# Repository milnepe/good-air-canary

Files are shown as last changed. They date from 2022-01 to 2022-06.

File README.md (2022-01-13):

# good-air-canary
An Arduino IoT client for DesignSpark ESDK that reacts to environmental C02 levels

Full details of the build can be found on [DesignSpark](https://www.rs-online.com/designspark/good-air-canary-build-guide).
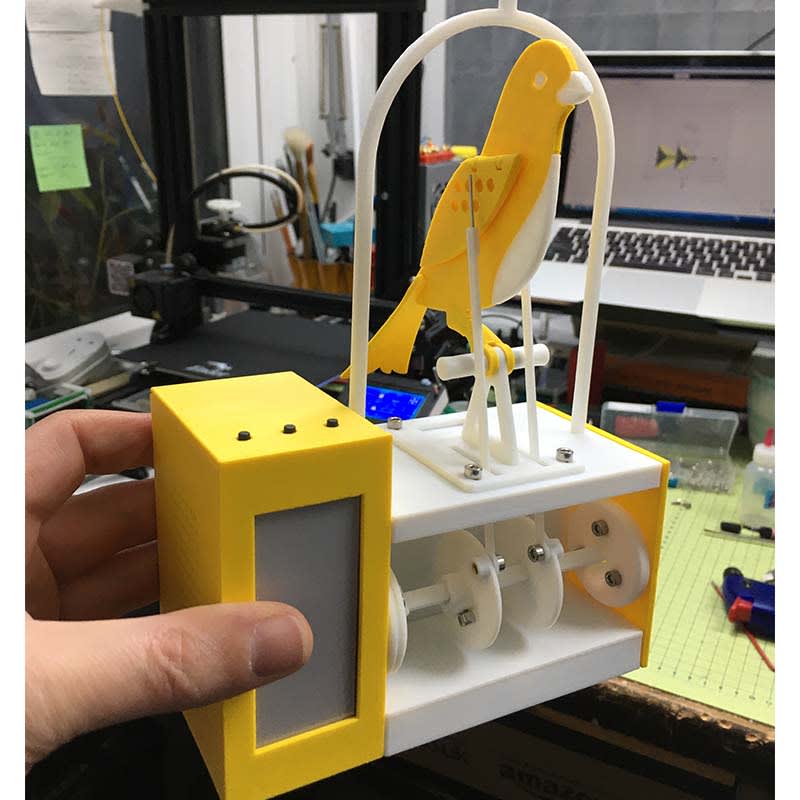
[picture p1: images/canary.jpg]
Canary


Prototype circuit in article on [DesignSpark](https://www.rs-online.com/designspark/the-good-air-canary-controller-build-guide).
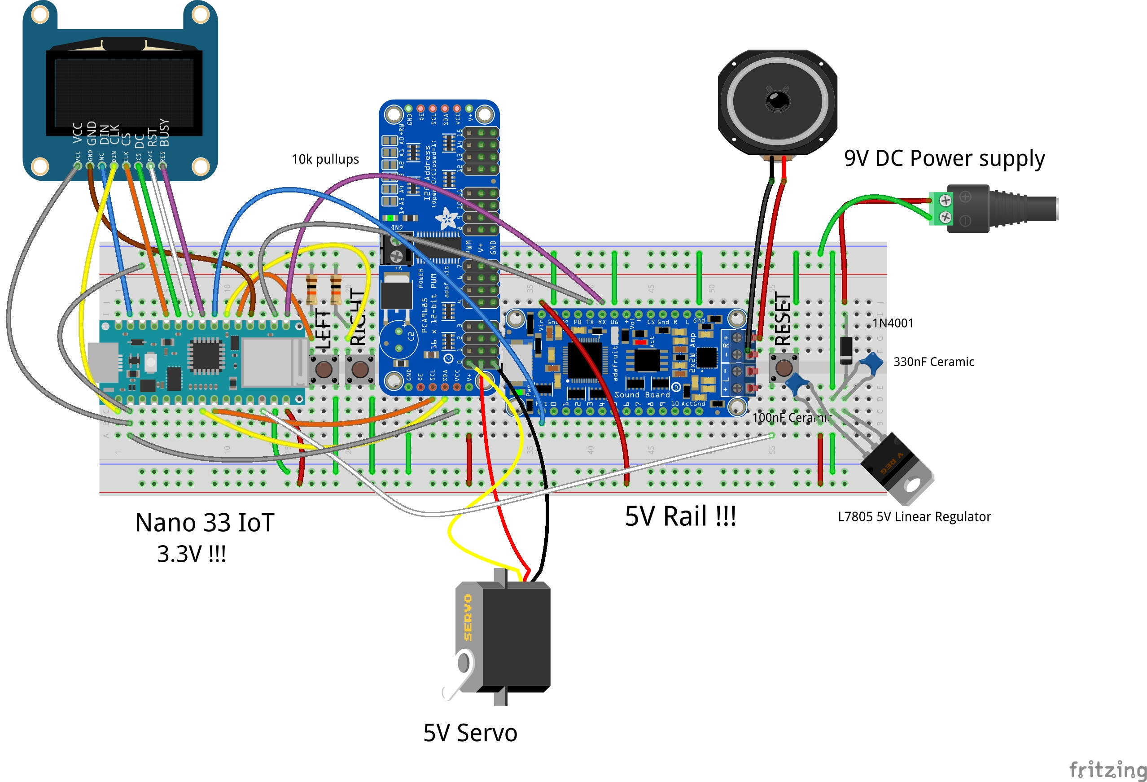
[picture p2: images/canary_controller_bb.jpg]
Canary controller circuit


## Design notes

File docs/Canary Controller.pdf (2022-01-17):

# The Good Air Canary Controller

An Arduino IoT client for DesignSpark ESDK that reacts to environmental CO2 levels

The DesignSpark Environmental Sensor Development Kit (ESDK) uses its attached sensors to collect CO2 levels in the surrounding environment. It sends this to a cloud dashboard so the data can be viewed and analysed.

Jude Pullen came up with the idea to create a model canary that could react to different levels of CO2 in the atmosphere and perform animations, like flapping its wings and falling off the perch when things got really bad. We also gave it a voice, just for good measure.

The device is really an IoT client for the ESDK. It’s powered by an Arduino microcontroller that receives messages containing the sensor readings via WiFi every time the ESDK updates them. The canary checks the CO2 level and if it’s too high it triggers one of its actions. For example, flapping its wings gently and asking you to open a window politely.

If you ignore its advice, it will become more and more agitated and vocal, before diving off its perch when it can take no more. If it gets to this stage, you really should open the windows for your own well being!

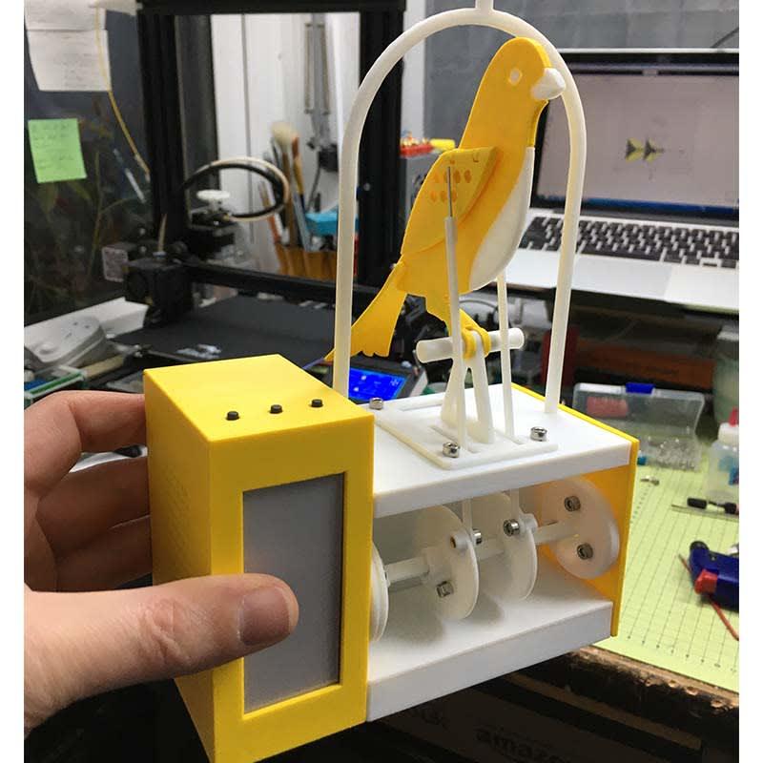
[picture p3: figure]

Difficulty: Medium

Steps: 7

Credit: Pete Milne

License: GNU Lesser General Public License

Parts Needed:

Part | Description | Stock No | Cost
Nano 33 IOT | https://uk.rs-online.com/web/p/arduino/1927589/ Available with and without headers. | 192-7589 | £18.04
5V Servos | TowerPro Servo Motor - SG90 Analog (https://thepihut.com/products/towerpro-servo-motor-sg90-analog) | 103049 | £4.00
Servo Driver | Adafruit 16-Channel 12-bit PWM/Servo Driver - I2C interface (https://www.adafruit.com/product/815) | ADA815 | £14.50
Sound board + Amp | Adafruit Audio FX Sound Board + 2x2W Amp - WAV/OGG Trigger - 2MB (https://www.adafruit.com/product/2217) | ADA2210 | £24.10
Speakers | Stereo Enclosed Speaker Set - 3W 4 Ohm (https://thepihut.com/products/stereo-enclosed-speaker-set-3w-4-ohm) RS have speakers in stock which may also be suitable | 102797 | £ 6.50
5V Linear Regulator | STMicroelectronics, 5 V Linear Voltage Regulator, 1A, 1-Channel, 2% 3-Pin, TO-220 L7805ABV (https://uk.rs-online.com/web/p/voltage-regulators/1686612/) | 686-9820 | £0.42
1N4001 Diode | Vishay 50V 1A, Diode, 2-Pin DO-204AL 1N4001-E3/54 (https://uk.rs-online.com/web/p/schottky-diodes-rectifiers/6288931/) | 628-8931 | £0.18
0.33uF Cap | 0.33uF Ceramic Capacitor
0.1uF Cap | 0.1uf Ceramic Capacitor
Power Supply | 9V / 500mA DC power supply or similar
Power Supply Connector | Female DC Power adapter - 2.1mm jack to screw terminal block (https://www.amazon.co.uk/Adafruit-2-1mm-Female-Terminal-Adapter/dp/B00KAE1QGS) | 102858 | £1.70
E-Ink Display | 296x128, 2.9inch E-Ink display module (https://www.waveshare.com/product/displays/e-paper/epaper-2/2.9inch-e-paper-module.htm) | | £20.00
Breadboard | Generic breadboard

# Step 1: Arduino MCU

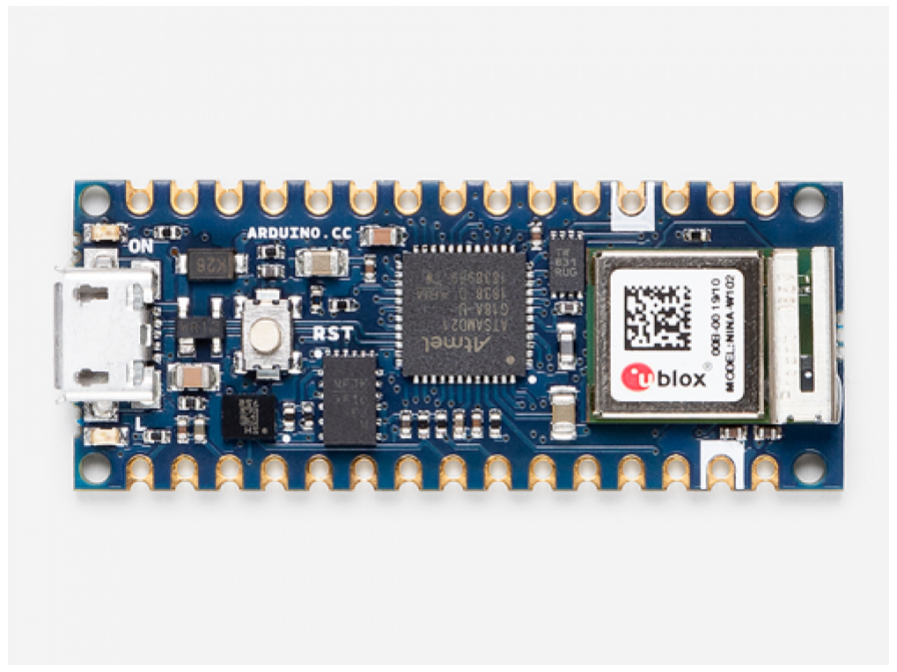
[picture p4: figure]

At the centre of the hardware is the Arduino Nano 33 IoT board. This has a SAMD21 Cortex®-M0+ 32bit ARM MCU with 256KB flash memory and a u-blox NINA-W102 Wifi module.

The board connects to Wifi, runs an MQTT client that receives the sensor data from the ESDK, processes the JSON messages and controls a servo to actuate the canary through a clever mechanical mechanism. The servo is driven by a PWM servo control board and high quality audio is provided by a dedicated audio board with a built in amplifier and single speaker attached.

# Step 2: Prototype circuit

The circuit can be built up and tested in stages to make sure that each component is working before adding the next. Just take care with voltage levels. Here are the main components:

Warning: The Arduino Nano GPIO operates at 3.3V and the circuit also uses 5V for some components - be careful not to connect 5V to the Arduino GPIO or you will damage it!

- Adafruit 16-Channel 12-bit PWM Servo Driver

This board operates at 3.3V (VCC) powered from the 3.3V pin on the Arduino. The servo has a separate 5V supply (V+) from the linear regulator. Communication is via an I2C interface using a driver library from the manufacturer. Originally we thought that we might need more than one servo for the canary, as it worked out we didn’t but we left the board in the design as it simplifies the hardware and programming.

- TowerPro SG90 Analog Servo Motor

This operates the wing mechanism of the canary

- Adafruit Audio 2MB FX Sound Board with Amp

Plays 44.1KHz 16 bit OGG format sound clip recordings that are pre-loaded onto the device in USB mass storage mode. It uses a serial interface operating at 9600 baud controlled by the Arduino using a driver library provided by the manufacturer.

- 4 Ohm / 3W Stereo Enclosed Speaker

We purchased a set of two speakers as the sound board supports stereo but it was decided to just use the one speaker for a compact design.

Note: Use 4 - 8 Ohm impedance speakers and to keep the cable length to less than 10 cm

- L7805 powers linear regulator and capacitors

We built in an independent 5V power supply to power the Arduino (via VIN) and for the audio board and servo. You may be able to get away with using the USB connector on the Arduino to supply the circuit, depending on your servo power requirements but it will be at the upper limit safe to use with the Arduino.

- 2.9 inch E-ink display from Waveshare

We wanted a contemporary display to show all the sensor readings received from the ESDK. The display was tricky to program and we had issues with the hardware versions being different, even though they had the same part number. The code libraries also seem to change during development so we have included the working version in our GitHub for the project.

Note: The E-ink display code and library version only works for Waveshare 2.9in Black & White displays marked V2

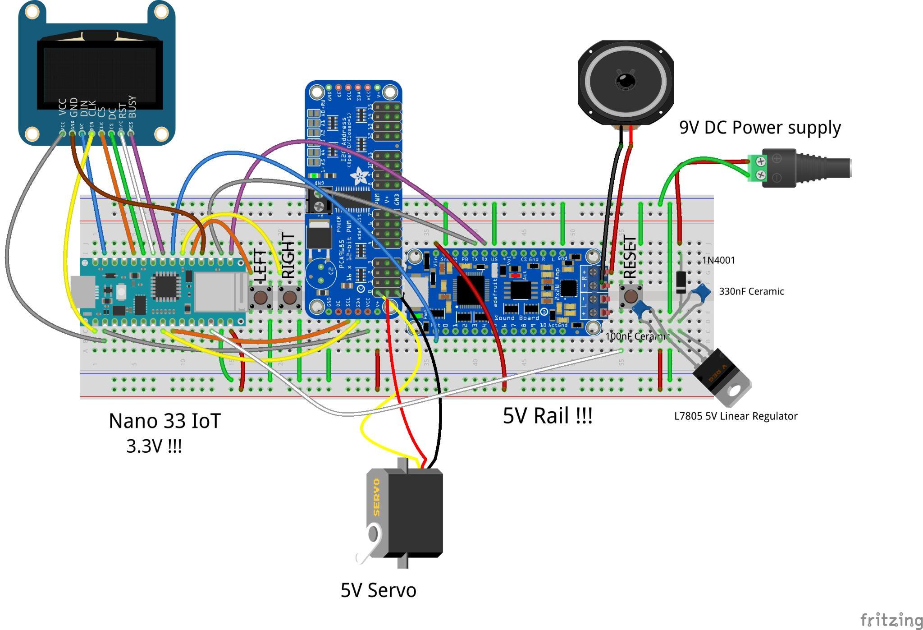
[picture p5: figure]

Here’s an image of the prototype circuit being tested with an early prototype the ESDK - you can see the ESDK between the screen and keyboard and the canary circuit to the right. The screen is showing the JSON messages being received from the ESDK in the Terminal.

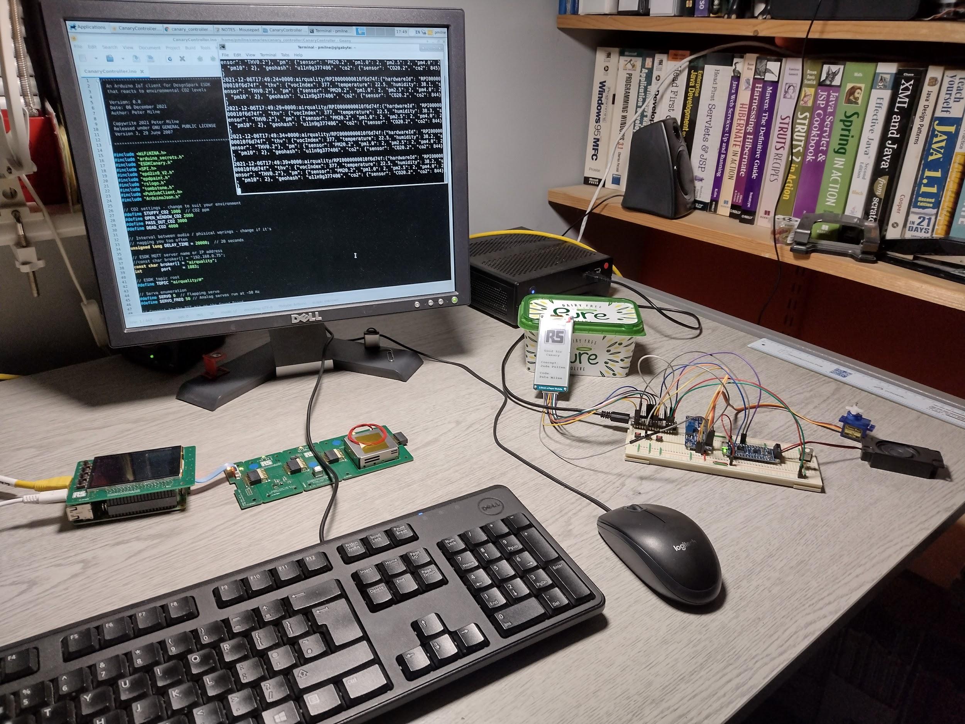
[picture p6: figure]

# Step 3: Arduino sketch

Programming and flashing the Arduino IDE was done using the Arduino IDE. The full source code is available on the DesignSpark GitHub:

https://github.com/DesignSparkRS/good-air-canary

Download the zip file or clone the repo to your Windows / Mac / Linux or Raspberry Pi.

You will need to install a number of different Libraries into the IDE using the Library Manager before you can compile and upload the code to the Arduino:

- Arduino WiFiNINA library
- Adafruit Soundboard library
- Adafruit PWM Servo Driver Library
- ArduinoJson - not Arduino_JSON which didn’t handle the large JSON payload well
- PubSubClient

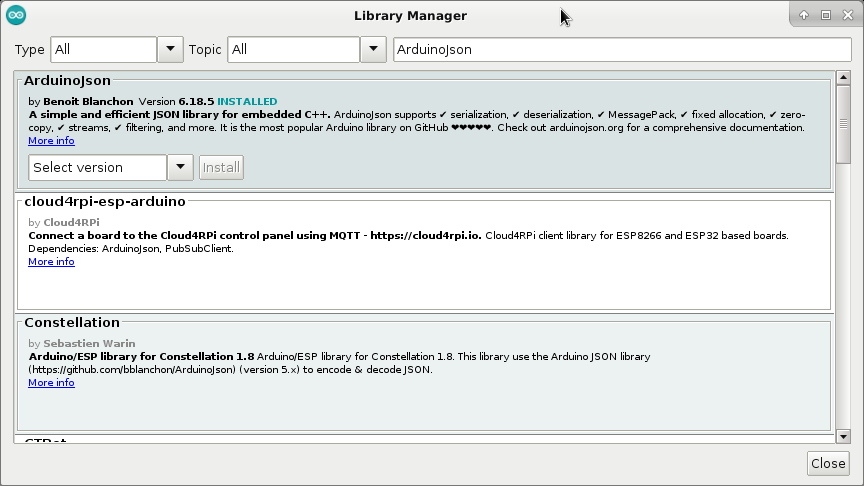
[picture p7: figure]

Attaching the Arduino to your Wifi will require editing the following lines in the arduino_secrets.h file which should appear in one of the tabs in the IDE.

Change the define statements to match your own Wifi SSID & password (with inverted commas):

### #define SECRET_SSID "YOURSSID"

### #define SECRET_PASS "YOURPASSWORD"

Depending on your network, you may need to change the default hostname of the ESDK. This is in CanaryController.ino. Change the character string from “airquality” the IP address of the ESDK on your network. You can find this by logging into your router as administrator and looking at the connected devices.

### // ESDK server name or IP address

//const char broker[] = "192.168.0.75";
const char broker[] = "airquality";

You can change the frequency with which the canary checks CO2 levels. For testing we set it to every 20 seconds but you may want to extend this by updating the define statement, in milli-seconds:

### // Interval between audio / physical warings - change if it's

### // nagging you too often

### unsigned long DELAY_TIME = 20000; // 20 seconds

Once all these changes have been made you should be able to compile and upload the code to your Arduino, then open the serial monitor to see debugging information.

When the system boots it displays the credits screen, initialises the servo and sound board, then plays a “yawn” sound clip. The Arduino then tries to connect to the network and if successful, subscribes to the ESDK’s MQTT server, where it waits for the first messages to appear. At that point the screen will start to display the sensor readings from the ESDK.

Periodically the canary evaluates the CO2 level data received and performs one of its actions according to the current level.

If you ignore the canary it will get persistently more agitated until it keels over. Don’t let that happen as it’s bad for your health and you will have to reset the Arduino, which is intentional!

# Step 4: MQTT

If you have a Linux box or a Raspberry Pi you can view the MQTT message payload coming from the ESDK by subscribing to its MQTT server.

Make sure you have the mosquitto-clients package installed:

### sudo apt install mosquitto-clients

Subscribe to the ESDK service using the following command:

### mosquitto_sub -F '%I:%t:%p' -h airquality -t airquality/#

You should see the JSON payload update every 5 seconds, similar to the output below:

# Step 5: Servo tuning

Each servo behaves slightly differently so you may need to tune the parameters to suit your servo. Do this by adjusting the following define statements in the ESDKCanary.h file which should appear as one of the tabs in your IDE:

### #define WINGS_DOWN 495

### #define WINGS_UP 445

### #define PASS_OUT_POS 225

### #define DEAD_POS 150

Tweak the settings by a small amount and then re-compile your code until the canary movement is correct and your servo is not chattering.

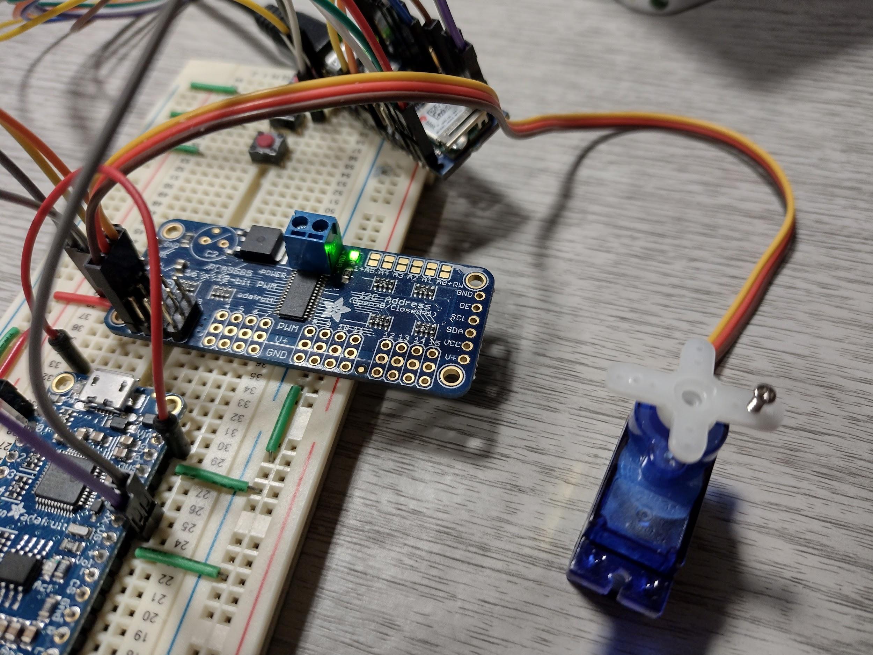
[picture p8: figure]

# Step 6: Sound effects

Our sound effect files were recorded on a windows PC in M4A format. They were converted to Ogg Vorbis format on a Linux box or Raspberry Pi using ffmpeg (other converters are available).

Make sure the ffmpeg package is installed:

## sudo apt install ffmpeg

This command, used in the Terminal converts the “yawn” clip in M4A format to the Ogg Vorbis format using the naming convention required by the sound board:

## ffmpeg -i yawn.m4a T00.ogg

The board can play upto 9 different files, which must have a specific naming convention. The first file is named T00.ogg, second T01.ogg etc.

Before the board is installed into the circuit, flash the Ogg sound clips onto the soundboard’s EPROM by attaching it to your PC with a USB cable and copying the files using a file manager or terminal.

You can record your own sound effects or use the ones provided in a Pytonesque voice over - let your creative side go wild!

Small 4 Ohm / 3 W speaker attached on short cable

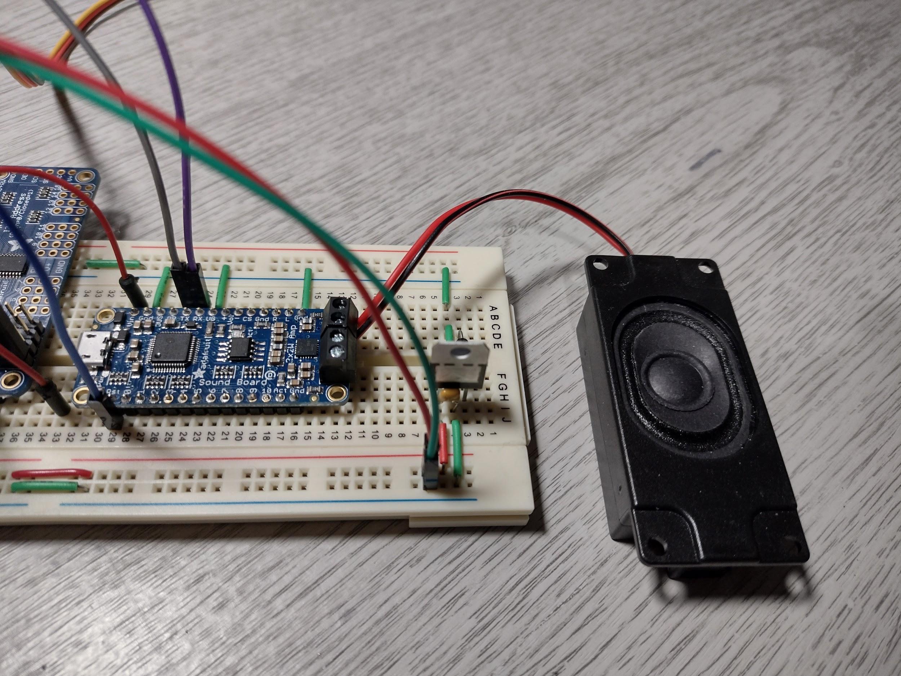
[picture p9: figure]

# Step 7: Buttons

There are now 2 buttons (Left & Right) which can be used to enable / disable the audio. They use 10k external pullup resistors and are connected to GND.

Left Button: Pin D2 -> Button -> GND

Right Button: Pin D3 -> Button -> GND

The Centre button is connected to the Arduino Reset pin and GND. This resets the whole board. When the screen clears for 5 seconds is a good time to disconnect the power to preserve the e-paper display.

Centre button: Reset -> Button -> GND

# Step 8: Troubleshooting

The Arduino IDE serial monitor is your friend when finding out what’s going on with your firmware. We included loads of serial output to help with debugging.

If you have trouble, uncomment the DEBUG define at the top of CanaryController.ino and reflash the code. You will need to open the Serial Monitor before the code will run. You should see helpful error messages which will help in tracking down any issues.

## // Un-comment for all debug prints

## // You will also need to attach a serial monitor before

## // the system will start up

## #define DEBUG

Here are a few common issues and how to solve them:

- Arduino is not connecting to the network

Change the “airquality” hostname to the IP address of the ESDK and reflash the code.

- Canary screen continues to display the credits screen

Check that the ESDK is on the same network if you have more than one and that you can subscribe to its MQTT messages using the method in step 4.

- Canary is not moving correctly

Check the servo parameters are suitable for your servo as in Step 5

- The sound board makes a popping sound but sound clips don’t play

Check you have set it to use 9600 baud rate in the setup section of CanaryController.ino

- E-Ink display is blank

Check you have the V2 version of the 2.9in Waveshare display

- MQTT messages are not being processed

Make sure you have enough memory allocated to hold the JSON document in the MQTT callback function

### // ESDK sends a large JSON payload

### // - ensure you have enough memory allocated

StaticJsonDocument<384> doc;

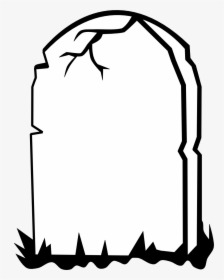
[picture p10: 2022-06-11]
images/tombstone.jpg

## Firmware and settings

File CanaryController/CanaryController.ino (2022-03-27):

/***************************************************
  An Arduino IoT client for DesgnSpark ESDK
  that reacts to environmental CO2 levels

  Version: 2.0
  Date: 27 March 2022
  Author: Peter Milne

  Copyright 2022 Peter Milne
  Released under GNU GENERAL PUBLIC LICENSE
  Version 3, 29 June 2007

 ****************************************************/
// Un-comment for debugging
// In debug mode the system will not run until a serial monitor
// is attached!
//#define DEBUG

#include <WiFiNINA.h>
#include "arduino_secrets.h"
#include "ESDKCanary.h"
#include <SPI.h>
#include "epd2in9_V2.h"
#include "epdpaint.h"
#include "rslogo.h"
#include "tombstone.h"
#include <PubSubClient.h>
#include "ArduinoJson.h"

// CO2 levels - change to suit your environment
#define STUFFY_CO2 1000  // CO2 ppm
#define OPEN_WINDOW_CO2 2000
#define PASS_OUT_CO2 3000
#define DEAD_CO2 4000

#define NORMAL_DELAY 30 * 60 * 1000  // 30 mins default
#define DEMO_DELAY 10 * 1000    // 10 sec for debug

#ifdef DEBUG
volatile unsigned long delay_time = DEMO_DELAY;
#else
// Interval between audio / physical warnings - change if it's
// nagging you too often
unsigned long delay_time = NORMAL_DELAY;
#endif
unsigned long previousMillis = 0;

// ESDK MQTT server name
// You may need to substiture its IP address on your network
//const char broker[] = "192.168.0.75";
const char broker[] = "airquality";
int        port     = 1883;

// ESDK topic root
#define TOPIC "airquality/#"

#define SERVO 0  // Flapping servo
#define SERVO_FREQ 50 // Analog servos run at ~50 Hz

// Connect to the RST pin on the Sound Board
#define SFX_RST 4

#define COLORED     0
#define UNCOLORED   1

unsigned char image[1024];
Paint paint(image, 0, 0);    // width should be the multiple of 8
Epd epd; // default reset: 8, dc: 9, cs: 10, busy: 7

/////// Enter sensitive data in arduino_secrets.h
char ssid[] = SECRET_SSID;  // Network SSID
char pass[] = SECRET_PASS;  // WPA key

WiFiClient wifiClient;
long lastReconnectWIFIAttempt = 0;
PubSubClient mqttClient(wifiClient);
long lastReconnectMQTTAttempt = 0;

Adafruit_PWMServoDriver pwm = Adafruit_PWMServoDriver();  // Default address 0x40

Adafruit_Soundboard sfx = Adafruit_Soundboard(&Serial1, NULL, SFX_RST);

ESDKCanary myCanary = ESDKCanary();

//unsigned long delayStart = 0; // time the delay started
bool delayRunning = false; // true if still waiting for delay to finish

volatile int co2 = 400;
double temperature = 21.0;
double humidity = 40.0;
int tvoc = 100;
int pm = 1;

volatile bool updateDisplayFlag = false;
bool tombstoneFlag = false;

uint16_t pulselen = 0;
int prevSensorValue = 0;

enum states {NORMAL, STUFFY, OPEN_WINDOW, PASS_OUT, THATS_BETTER, DEAD} state = NORMAL;
enum states previousState = NORMAL;

// Button code
enum buttons {LEFT_BUTTON = 2, RIGHT_BUTTON = 3, DEMO_BUTTON = 9};
volatile boolean audioOn = true;
volatile boolean demo_mode = false;
volatile boolean reentrant = true;

int wifiState = WL_IDLE_STATUS;

void setup() {
  // Setup buttons
  pinMode(LEFT_BUTTON, INPUT);
  pinMode(RIGHT_BUTTON, INPUT);
  pinMode(DEMO_BUTTON, INPUT);
  //  pinMode(isrLED, OUTPUT);
  //  digitalWrite(isrLED, HIGH);
  attachInterrupt(digitalPinToInterrupt(LEFT_BUTTON), leftButtonIsr, FALLING);
  // DEMO_BUTTON duplicates the RIGHT_BUTTON function - activates demo
  attachInterrupt(digitalPinToInterrupt(RIGHT_BUTTON), rightButtonIsr, FALLING);
  attachInterrupt(digitalPinToInterrupt(DEMO_BUTTON), rightButtonIsr, FALLING);

  Serial.begin(115200);
#ifdef DEBUG
  while (!Serial) {
    ; // wait for serial port to connect
  }
#endif
  Serial.println("Canary Controller");

  Serial1.begin(9600);
  while (!Serial1) {
    ; // wait for serial port to connect
  }
  Serial.println("Serial1 attached");

  if (epd.Init() != 0) {
    Serial.print("e-Paper init failed ");
    return;
  }
  Serial.println("EDP attached");

  epd.ClearFrameMemory(0xFF);   // bit set = white, bit reset = black
  epd.DisplayFrame();

  /**
      there are 2 memory areas embedded in the e-paper display
      and once the display is refreshed, the memory area will be auto-toggled,
      i.e. the next action of SetFrameMemory will set the other memory area
      therefore you have to set the frame memory and refresh the display twice.
  */
  epd.SetFrameMemory_Base(RSLOGO);
  epd.DisplayFrame();

  updateEPDGreeting();

  // Setup sound board
  if (!sfx.reset()) {
    Serial.println("SFX board not found");
    //while (1);
  }
  else Serial.println("SFX board attached");
  myCanary.Tweet(sfx, YAWN_TRACK);

  // Setup servo
  pwm.begin();
  pwm.setOscillatorFrequency(27000000);
  pwm.setPWMFreq(SERVO_FREQ);  // Analog servos run at ~50 Hz updates
  myCanary.ServoInit(pwm, SERVO);
  Serial.println("Servo initialised");

  Serial.print("Attempting to connect to the MQTT broker: ");
  Serial.println(broker);

  mqttClient.setServer(broker, port);
  mqttClient.setCallback(callback);
  mqttClient.setBufferSize(384);

  delay(5000);
}

void loop() {
  if (demo_mode) {
    if (WiFi.status() == WL_CONNECTED) {
      mqttClient.disconnect();
      WiFi.disconnect();
      wifiState = WiFi.status();
      delay(1000);
    }

  } else {  // WiFi mode
    // Attempt to reconnect - Wifi.begin blocks until connect or failure
    if (WiFi.status() != WL_CONNECTED) {
      Serial.println("WiFi mode...");
      updateEPD();
      reconnectWiFi();
    }

    // Attempt to reconnect without blocking
    if (!mqttClient.connected()) {
      long now = millis();
      if (now - lastReconnectMQTTAttempt > 5000) {
        lastReconnectMQTTAttempt = now;
        if (reconnectMQTT()) {
          lastReconnectMQTTAttempt = 0;
        }
      }
    } else {
      mqttClient.loop();
    }
  }  // end demo

  if (updateDisplayFlag) {
    updateDisplayFlag = false;
    updateEPD();
  }

  unsigned long currentMillis = millis();
  if (currentMillis - previousMillis >= delay_time) {
    previousMillis = currentMillis;
    updateCanary();
  }
}

void updateCanary() {
  switch (state = getState(previousState, co2)) {
    case 0: // Normal do nothing
      if (demo_mode) {
        co2 += 1000;
        updateDisplayFlag = true;
      }
      break;
    case 1: // Stuffy
      Serial.println("Stuffy...");
      if (demo_mode) {
        co2 += 1000;
        updateDisplayFlag = true;
      }
      if (audioOn) {
        myCanary.Tweet(sfx, STUFFY_TRACK);
      }
      myCanary.Flap(pwm, SERVO);
      myCanary.Flap(pwm, SERVO);
      myCanary.Flap(pwm, SERVO);
      break;
    case 2: // Open a window
      Serial.println("Open a window...");
      if (demo_mode) {
        co2 += 1000;
        updateDisplayFlag = true;
      }
      if (audioOn) {
        myCanary.Tweet(sfx, OPEN_WINDOW_TRACK);
      }
      myCanary.OpenWindow(pwm, SERVO);
      myCanary.OpenWindow(pwm, SERVO);
      myCanary.OpenWindow(pwm, SERVO);
      break;
    case 3: // Pass out
      Serial.println("Pass out...");
      if (demo_mode) {
        co2 += 1000;
        updateDisplayFlag = true;
      }
      if (audioOn) {
        myCanary.Tweet(sfx, PASS_OUT_TRACK);
      }
      myCanary.PassOut(pwm, SERVO);
      break;
    case 4: // Thats better
      Serial.println("That's better...");
      if (audioOn) {
        myCanary.Tweet(sfx, THATS_BETTER_TRACK);
      }
      myCanary.ThatsBetter(pwm, SERVO);
      break;
    case 5: // Dead
      Serial.println("Dead...");
      if (audioOn) {
        myCanary.Tweet(sfx, DEAD_TRACK);
      }
      if (demo_mode) {
        myCanary.PassOut(pwm, SERVO);
        displayTombStone();
        delay(5000);
        displayClear();
        co2 = 400;
        updateDisplayFlag = true;
        demo_mode = false;
//        myCanary.SlowInit(pwm, SERVO);
        delay(2000);        
#ifdef DEBUG
        delay_time = DEMO_DELAY;
#else
        delay_time = NORMAL_DELAY;
#endif
        updateCanary();
      } else {
        myCanary.Dead(pwm, SERVO);
        displayTombStone();
        delay(5000);
        displayClear();
        while (1);// Program ends!! Reboot
        //        tombstoneFlag = true;
      }
  }
  previousState = state;
}

// Toggle audio on / off
void leftButtonIsr() {
  audioOn = ! audioOn;
  updateEPD();
}

// Enter demo mode
void rightButtonIsr() {
  demo_mode = true;
  delay_time = DEMO_DELAY;
  audioOn = true;
  co2 = 400;
  reentrant = true;
}

// Sets the rules for changing state
states getState(states previousState, int co2) {
  states state;
  if ((previousState == PASS_OUT) && (co2 < PASS_OUT_CO2)) {
    state = THATS_BETTER;
  }
  else if (co2 < STUFFY_CO2) {
    state = NORMAL;
  }
  else if (co2 < OPEN_WINDOW_CO2) {
    state = STUFFY;
  }
  else if (co2 < PASS_OUT_CO2) {
    state = OPEN_WINDOW;
  }
  else if (co2 < DEAD_CO2) {
    state = PASS_OUT;
  }
  else state = DEAD;
  return state;
}

void reconnectWiFi() {
#ifdef DEBUG
  Serial.print("Wifi Status: ");
  Serial.println(WiFi.status());
#endif
  // WL_IDLE_STATUS     = 0
  // WL_NO_SSID_AVAIL   = 1
  // WL_SCAN_COMPLETED  = 2
  // WL_CONNECTED       = 3
  // WL_CONNECT_FAILED  = 4
  // WL_CONNECTION_LOST = 5
  // WL_DISCONNECTED    = 6
  WiFi.disconnect();
  delay(1000);
  WiFi.begin(ssid, pass);
  delay(1000);
  wifiState = WiFi.status();
  Serial.println(WiFi.localIP());
}

boolean reconnectMQTT() {
  if (mqttClient.connect("arduinoClient")) {
    mqttClient.subscribe("airquality/#");
    Serial.println("MQTT connected");
  }
  return mqttClient.connected();
}

// Update sensor variables each time a message is received
void callback(char* topic, byte * payload, unsigned int length) {
#ifdef DEBUG
  Serial.print("Message arrived [");
  Serial.print(topic);
  Serial.print("] ");
  for (int i = 0; i < length; i++) {
    Serial.print((char)payload[i]);
  }
  Serial.println();
#endif
  // ESDK sends a large JSON payload
  // - ensure you have enough memory allocated
  StaticJsonDocument<384> doc;
  deserializeJson(doc, payload, length);
  co2 = doc["co2"]["co2"];
  temperature = doc["thv"]["temperature"];
  humidity = doc["thv"]["humidity"];
  tvoc = doc["thv"]["vocIndex"];
  pm = doc["pm"]["pm2.5"];

  updateDisplayFlag = true;
  if (reentrant) {
    reentrant = false;
    updateCanary();
  }
}

void updateEPDGreeting() {
  paint.SetWidth(120);
  paint.SetHeight(32);
  paint.SetRotate(ROTATE_180);

  paint.Clear(UNCOLORED);
  paint.DrawStringAt(0, 4, " Good Air", &Font16, COLORED);
  epd.SetFrameMemory_Partial(paint.GetImage(), 0, 140, paint.GetWidth(), paint.GetHeight());

  paint.Clear(UNCOLORED);
  paint.DrawStringAt(0, 4, "  Canary  ", &Font16, COLORED);
  epd.SetFrameMemory_Partial(paint.GetImage(), 0, 120, paint.GetWidth(), paint.GetHeight());

  paint.Clear(UNCOLORED);
  paint.DrawStringAt(0, 4, "Concept:", &Font16, COLORED);
  epd.SetFrameMemory_Partial(paint.GetImage(), 0, 80, paint.GetWidth(), paint.GetHeight());

  paint.Clear(UNCOLORED);
  paint.DrawStringAt(0, 4, "Jude Pullen", &Font16, COLORED);
  epd.SetFrameMemory_Partial(paint.GetImage(), 0, 60, paint.GetWidth(), paint.GetHeight());

  paint.Clear(UNCOLORED);
  paint.DrawStringAt(0, 0, "Code:", &Font16, COLORED);
  epd.SetFrameMemory_Partial(paint.GetImage(), 0, 20, paint.GetWidth(), paint.GetHeight());

  paint.Clear(UNCOLORED);
  paint.DrawStringAt(0, 0, "Pete Milne", &Font16, COLORED);
  epd.SetFrameMemory_Partial(paint.GetImage(), 0, 0, paint.GetWidth(), paint.GetHeight());

  epd.DisplayFrame_Partial();
}

void displayTombStone() {
  Serial.println("Tombstone!...");
  delay(2000);
  if (epd.Init() != 0) {
    Serial.print("e-Paper init failed ");
    return;
  }
  epd.SetFrameMemory_Base(TOMBSTONE);
  epd.DisplayFrame();
  tombstoneFlag = false;
  delay(5000);
}

void displayClear() {
  Serial.println("Clearing display...");
  delay(2000);
  if (epd.Init() != 0) {
    Serial.print("e-Paper init failed ");
    return;
  }
  epd.ClearFrameMemory(0xFF);   // bit set = white, bit reset = black
  epd.DisplayFrame();
  delay(2000);
  epd.ClearFrameMemory(0xFF);   // bit set = white, bit reset = black
  epd.DisplayFrame();
  delay(2000);
}

void updateEPD() {
  if (co2 > 9999) {
    co2 = 0;
  }
  char CO2_string[] = {'0', '0', '0', '0', 'p', 'p', 'm', '\0'};
  CO2_string[0] = co2 / 100 / 10 + '0';
  CO2_string[1] = co2 / 100 % 10 + '0';
  CO2_string[2] = co2 % 100 / 10 + '0';
  CO2_string[3] = co2 % 100 % 10 + '0';

  int temp = 0;
  if (temperature < 99.9) {
    temp = (int)(temperature * 10);
  }
  char TEMP_string[] = {'0', '0', '.', '0', 'C', '\0'};
  TEMP_string[0] = temp / 10 / 10 + '0';
  TEMP_string[1] = temp / 10 % 10 + '0';
  TEMP_string[3] = temp % 10 + '0';

  int hum = 0;
  if (humidity < 99.9) {
    hum = (int)(humidity * 10);
  }
  char RH_string[] = {'0', '0', '.', '0', '%', '\0'};
  RH_string[0] = hum / 10 / 10 + '0';
  RH_string[1] = hum / 10 % 10 + '0';
  RH_string[3] = hum % 10 + '0';

  if (tvoc > 9999) {
    tvoc = 0;
  }
  char TVOC_string[] = {'0', '0', '0', '0', 'p', 'p', 'm', '\0'};
  TVOC_string[0] = tvoc / 100 / 10 + '0';
  TVOC_string[1] = tvoc / 100 % 10 + '0';
  TVOC_string[2] = tvoc % 100 / 10 + '0';
  TVOC_string[3] = tvoc % 100 % 10 + '0';

  if (pm > 9999) {
    pm = 0;
  }
  char PART_string[] = {'0', '0', '0', '0', '\0'};
  PART_string[0] = pm / 100 / 10 + '0';
  PART_string[1] = pm / 100 % 10 + '0';
  PART_string[2] = pm % 100 / 10 + '0';
  PART_string[3] = pm % 100 % 10 + '0';

  paint.SetWidth(120);
  paint.SetHeight(32);
  paint.SetRotate(ROTATE_180);

  paint.Clear(UNCOLORED);
  paint.DrawStringAt(0, 4, "CO2", &Font24, COLORED);
  epd.SetFrameMemory_Partial(paint.GetImage(), 0, 260, paint.GetWidth(), paint.GetHeight());

  paint.Clear(UNCOLORED);
  paint.DrawStringAt(0, 4, CO2_string, &Font20, COLORED);
  epd.SetFrameMemory_Partial(paint.GetImage(), 0, 240, paint.GetWidth(), paint.GetHeight());

  paint.Clear(UNCOLORED);
  paint.DrawStringAt(0, 4, "TEMP", &Font24, COLORED);
  epd.SetFrameMemory_Partial(paint.GetImage(), 0, 210, paint.GetWidth(), paint.GetHeight());

  paint.Clear(UNCOLORED);
  paint.DrawStringAt(0, 4, TEMP_string, &Font20, COLORED);
  epd.SetFrameMemory_Partial(paint.GetImage(), 0, 190, paint.GetWidth(), paint.GetHeight());

  paint.Clear(UNCOLORED);
  paint.DrawStringAt(0, 0, "RH", &Font24, COLORED);
  epd.SetFrameMemory_Partial(paint.GetImage(), 0, 160, paint.GetWidth(), paint.GetHeight());

  paint.Clear(UNCOLORED);
  paint.DrawStringAt(0, 0, RH_string, &Font20, COLORED);
  epd.SetFrameMemory_Partial(paint.GetImage(), 0, 140, paint.GetWidth(), paint.GetHeight());

  paint.Clear(UNCOLORED);
  paint.DrawStringAt(0, 0, "TVOC", &Font24, COLORED);
  epd.SetFrameMemory_Partial(paint.GetImage(), 0, 110, paint.GetWidth(), paint.GetHeight());

  paint.Clear(UNCOLORED);
  paint.DrawStringAt(0, 0, TVOC_string, &Font20, COLORED);
  epd.SetFrameMemory_Partial(paint.GetImage(), 0, 90, paint.GetWidth(), paint.GetHeight());

  paint.Clear(UNCOLORED);
  paint.DrawStringAt(0, 0, "PM2.5", &Font20, COLORED);
  epd.SetFrameMemory_Partial(paint.GetImage(), 0, 60, paint.GetWidth(), paint.GetHeight());

  paint.Clear(UNCOLORED);
  paint.DrawStringAt(0, 0, PART_string, &Font20, COLORED);
  epd.SetFrameMemory_Partial(paint.GetImage(), 0, 40, paint.GetWidth(), paint.GetHeight());

  paint.Clear(UNCOLORED);
  if (demo_mode) {
    paint.DrawStringAt(0, 0, "Demo Mode", &Font16, COLORED);
  }
  else if ((audioOn) && (wifiState == WL_CONNECTED)) {
    paint.DrawStringAt(0, 0, "Wifi Audio", &Font16, COLORED);
  }
  else if (wifiState == WL_CONNECTED) {
    paint.DrawStringAt(0, 0, "Wifi", &Font16, COLORED);
  }
  else if (audioOn) {
    paint.DrawStringAt(0, 0, "Audio", &Font16, COLORED);
  }
  else {
    paint.DrawStringAt(0, 0, "", &Font16, COLORED);
  }
  epd.SetFrameMemory_Partial(paint.GetImage(), 0, 0, paint.GetWidth(), paint.GetHeight());

  epd.DisplayFrame_Partial();
}

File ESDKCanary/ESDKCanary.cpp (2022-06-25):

#include "ESDKCanary.h"

ESDKCanary::ESDKCanary(Adafruit_Soundboard *sfx, Adafruit_PWMServoDriver *pwm, int servo)
  :ESDKCanary(pwm, servo) {
  _sfx = sfx;
}

ESDKCanary::ESDKCanary(Adafruit_PWMServoDriver *pwm, int servo) {
  _pwm = pwm;
  _servo = servo;
  _pulselen = WINGS_START;
}

void ESDKCanary::updateCanary() {
  switch (state) {
    case THATS_BETTER:
      Tweet(THATS_BETTER_TRACK, audioOn);
      StartPos(WINGS_DOWN);
      break;
    case STUFFY:
      Tweet(STUFFY_TRACK, audioOn);
      Flap(WINGS_DOWN, WINGS_UP_A_BIT, VSLOW, 3);
      break;
    case OPEN_WINDOW:
      Tweet(OPEN_WINDOW_TRACK, audioOn);
      Flap(WINGS_DOWN, WINGS_UP_A_LOT, FAST, 4);
      break;
    case PASS_OUT:
      Tweet(PASS_OUT_TRACK, audioOn);
      PassOut(PASS_OUT_POS, FAST);
      break;
    case DEAD:
      if (!demoOn) {
        Tweet(DEAD_TRACK, audioOn);
        Dead(DEAD_POS, VFAST);
        while (1);// Program ends!! Reboot
      } else {
        StartPos(WINGS_DOWN);
        delay(2000);
        Tweet(DEAD_TRACK, audioOn);
        PassOut(PASS_OUT_POS, FAST);
        StartPos(WINGS_DOWN);
      }
  }
}

// Sets the rules for changing state
States ESDKCanary::updateState() {
  static States previousState = NORMAL;

  if ((previousState == PASS_OUT) && (co2 < PASS_OUT_CO2)) {
    state = THATS_BETTER;
  }
  else if ((previousState == OPEN_WINDOW) && (co2 < OPEN_WINDOW_CO2)) {
    state = THATS_BETTER;
  }
  else if (co2 < STUFFY_CO2) {
    state = THATS_BETTER;
  }
  else if (co2 < OPEN_WINDOW_CO2) {
    state = STUFFY;
  }
  else if (co2 < PASS_OUT_CO2) {
    state = OPEN_WINDOW;
  }
  else if (co2 < DEAD_CO2) {
    state = PASS_OUT;
  }
  else state = DEAD;

  // Update canary if state has changed
  if ( state != previousState ) {
    previousState = state;
    updateCanary();
  }
  return state;
}

void ESDKCanary::StartPos(uint16_t start_pos) {
  // Move wings to start position
  for (; _pulselen < start_pos; _pulselen++) {
    _pwm->setPWM(_servo, 0, _pulselen);
    delay(VSLOW);
  }
}

void ESDKCanary::Flap(uint16_t down_pos, uint16_t up_pos, int speed_idx, int flaps) {
  // Move wings back and fourth
  // Note that the value of pulselen is inverted!
  // speed_idx  0 is fastest

  for (int i = 0; i < flaps; i++) {
    // Up
    for (; _pulselen > up_pos; _pulselen--) {
      _pwm->setPWM(_servo, 0, _pulselen);
      delay(speed_idx);
    }
    delay(100);
    // Down
    for (; _pulselen < down_pos; _pulselen++) {
      _pwm->setPWM(_servo, 0, _pulselen);
      delay(speed_idx);
    }
    delay(100);
  }
}

void ESDKCanary::PassOut(uint16_t end_pos, int speed_idx) {
  // Move wings to pass out position and hold it
  // Note that the value of pulselen is inverted!

  for (; _pulselen > end_pos; _pulselen--) {
    _pwm->setPWM(_servo, 0, _pulselen);
    delay(speed_idx);
  }
}


void ESDKCanary::Dead(uint16_t end_pos, int speed_idx) {
  // Move servo past tipping point then retract wings.
  // This position should only be recovered by resetting the system

  for (; _pulselen > end_pos; _pulselen--) {
    _pwm->setPWM(_servo, 0, _pulselen);
    delay(speed_idx);
  }
}

void ESDKCanary::Tweet(uint8_t track, boolean audio = true) {
  if (audio) {
    if (! _sfx->playTrack(track)) {
      ;
    }
  }
}

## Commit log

2021-12-08 Add circuit diagram
    [canary_controller.fzz]
2022-01-12 Add button interrupts
    Left button turns sound on / Right off
    Also improved WiFi / MQTT reconnect functions
2022-01-13 Add buttons to Fritzing diagram
    Left button enables (default) audio, right button
    disables audio. Centre button resets Arduino.
    [canary_controller.fzz]
2022-01-17 Change button setup to reflect external pullups
2022-01-17 Add external 10k pullups to diagrams
    [canary_controller.fzz]
2022-03-04 Move audio toggle function to single button
2022-03-22 Add external demo button
    This duplicates the right button function
2022-03-23 Refactor demo
    Demo mode reverts to WiFi mode after demo cycle ends
    [CanaryController.ino]
2022-05-08 Improved servo control
    Pulse length now tracked in Canary object
    plus addition of ServoTest example
2022-05-09 Add sound board support to ServoTest
2022-05-11 Fix MQTT disconnect
    Check Wifi is connected before trying to connect MQTT client
    [CanaryController.ino]
2022-05-11 Add heartbeat led
2022-05-13 Added MQTT test example
    Hopefully this will help identify why the MQTT client
    fails to reconnect after 24Hrs or so
    [mqtt_reconnect_nonblocking.ino]
2022-05-13 Added led status lights
2022-05-15 Add MQTT reconnect test for ESDK payload
    Added new test using ArduinoJson parser
2022-06-11 Refactor display into own class
    Todo - make display an interface
    - fix audio / wifi status on display
    [CanaryController.ino]
2022-06-27 Update servo positions
